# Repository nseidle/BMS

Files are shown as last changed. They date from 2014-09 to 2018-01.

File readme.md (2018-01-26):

Battery Management System
=======

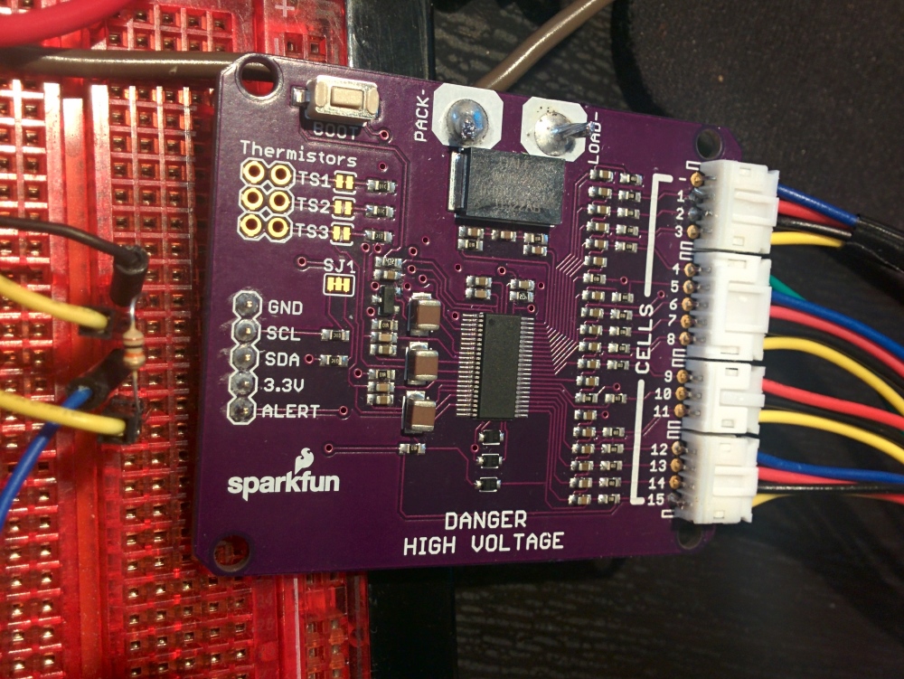
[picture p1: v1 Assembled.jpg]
BMS PCB Assembled v1


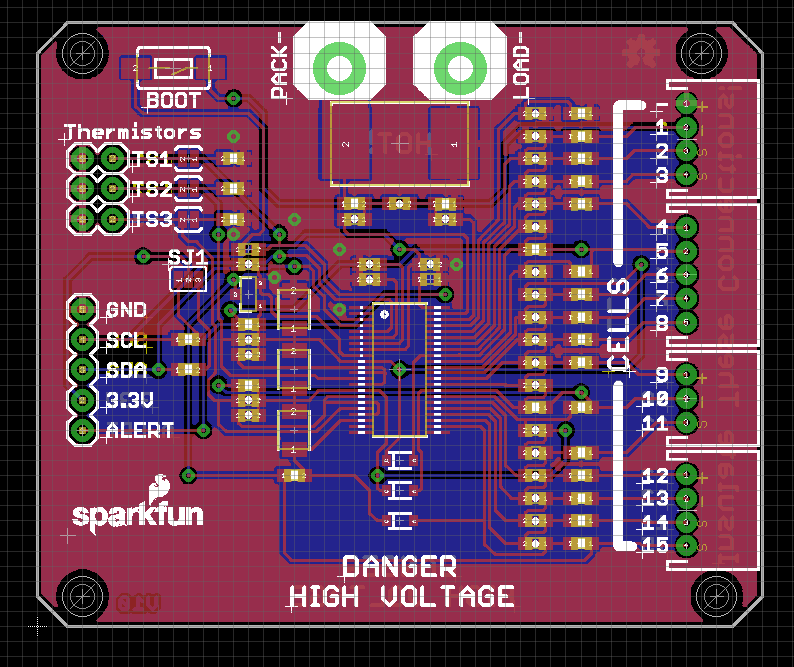
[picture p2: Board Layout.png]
BMS PCB Layout


This is a breakout board for the BQ76940. This configuration allows for 15 cells to be read. There is no safety cut off.

This is a dangerous board that exposes the user to over 48VDC and many amps. Please use responsibly.

v1 of the board is functional. Firmware is working. Most functions are written. 

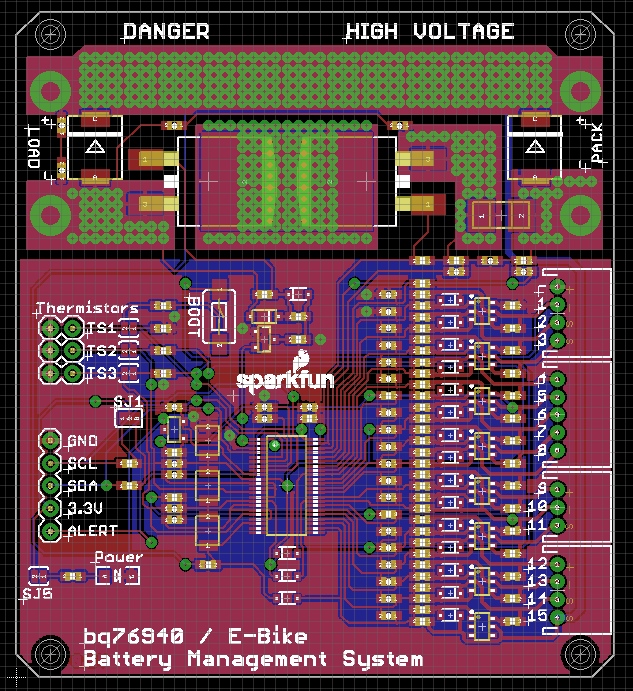
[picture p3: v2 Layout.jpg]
BMS PCB Layout v2


-> v2 of the board has full cutoff MOSFETs and charging MOSFETs. <-

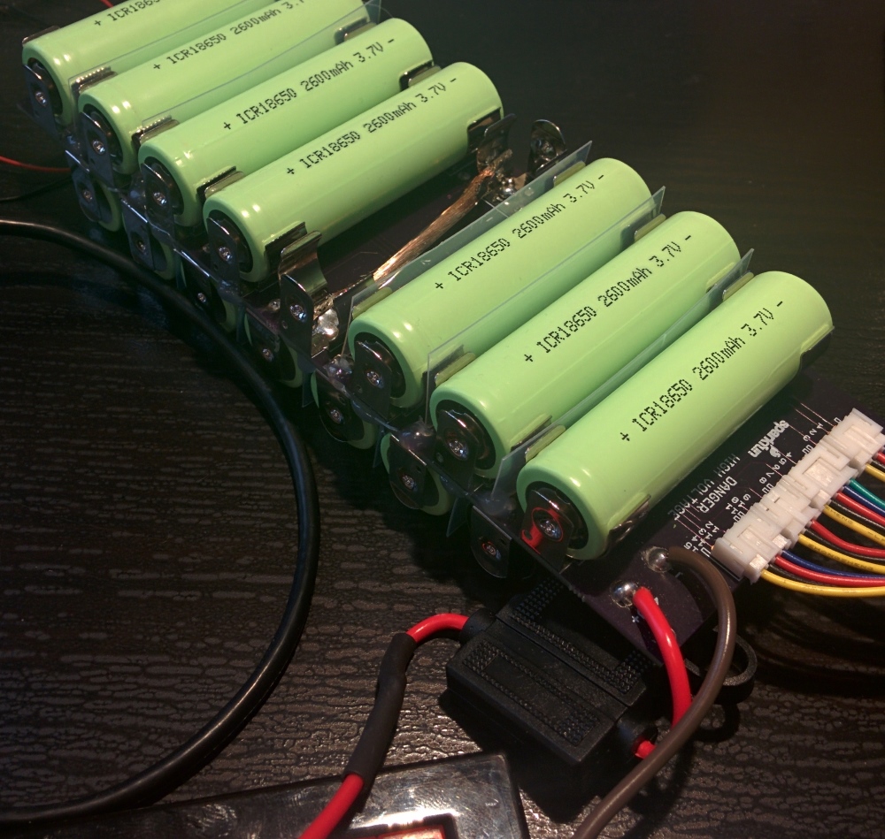
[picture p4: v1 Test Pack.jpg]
BMS Test Pack v1


v1 of the test pack works but has multiple errors that are fixed on v2. Number labels on the cells are reversed. Cells 9 and 14 were shorted to bring the voltage back down to 48V. The clips are very close together so plastic insulators were glued in place.

License Information
-------------------

This code is public domain but you buy me a beer if you use this and we meet someday ([Beerware license](http://en.wikipedia.org/wiki/Beerware)).

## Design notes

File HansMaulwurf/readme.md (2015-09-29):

Hans Maulwurf Project
=======

This is a university project created by Hans Maulwurf based on the original project by Nathan Seidle. This project documentation may aid others working with the BQ76940.

- Uses the ATmega168PA
- Programming was done in C with Linux in nano and the AVR-Tools (avr-gcc, avr-objcopy, avrdude, make)
- The system has 15 cells and max, 60 Volts

License Information
-------------------

Hans has agreed to release this portion of his project under the same licensing as the original project. This code is public domain but you buy me a beer if you use this and we meet someday ([Beerware license](http://en.wikipedia.org/wiki/Beerware)).

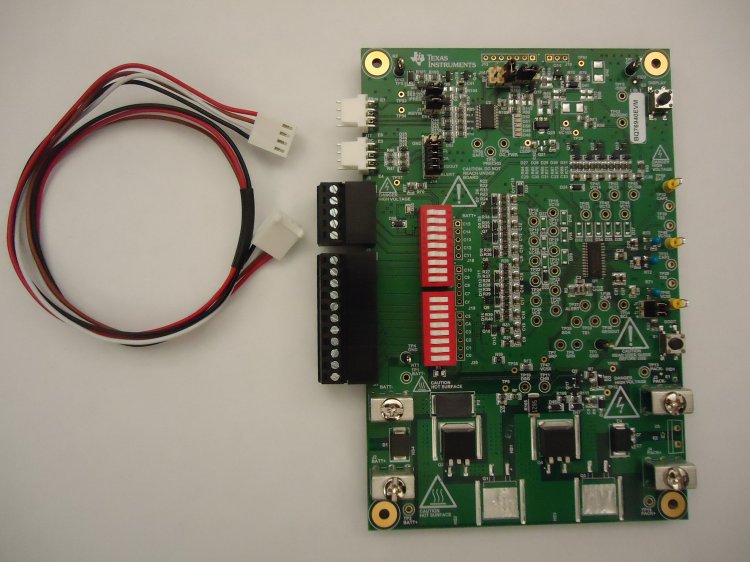
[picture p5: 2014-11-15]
datasheets/bq76940evm_bq76940evm.JPG

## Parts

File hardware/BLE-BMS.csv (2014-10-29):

Qty | Value | Device | Package | Parts | Description | PROD_ID | SKU | VALUE
1 | .001 | RESISTORWSR | 4527 | R29
3 | 0.1uF | 0.1UF-25V(+80/-20%)(0603) | 0603-CAP | C29, C30, C31 | CAP-00810 | CAP-00810 |  | 0.1uF
5 | 100 | 100OHM1/10W1%(0603) | 0603-RES | R3, R27, R28, R30, R31 | RES-07863 | RES-07863 |  | 100
5 | 10k | 10KOHM1/10W1%(0603)0603 | 0603-RES | R1, R2, R32, R33, R34 | RES-00824 | RES-00824 |  | 10K
3 | 10uF | 10UF50V20%(1210) | 1210 | C32, C33, C34 | CAP-09824 | CAP-09824 |  | 10uF
18 | 1K | 1KOHM1/10W1%(0603) | 0603-RES | R4, R5, R6, R10, R11, R12, R13, R14, R15, R16, R17, R18, R19, R20, R21, R22, R23, R24 | RES-07856 | RES-07856 |  | 1K
22 | 1uF | 1.0UF-16V-10%(0603) | 0603-CAP | C4, C6, C7, C8, C11, C12, C13, C14, C15, C16, C17, C18, C19, C20, C21, C22, C23, C24, C25, C26, C27, C28 | CAP-00868 | CAP-00868 |  | 1.0uF
2 | 4.7k | 4.7KOHM1/10W1%(0603) | 0603 | R25, R26 | RES-07857 | RES-07857
1 | 4.7uF | 4.7UF-6.3V-10%(0603)0603 | 0603-CAP | C1 | CAP-08280 | CAP-08280 |  | 4.7uF
3 | 4700pF | 4.7NF-50V-10%(0603) | 0603-CAP | C2, C9, C10 | CAP-11378 | CAP-11378 |  | 4.7nF
3 | BAS16 | DIODESOD | SOD-323 | D1, D2, D3 | Diode | DIO-09646
1 | BOOT | SWITCH-MOMENTARY-2-SMD-1101NE | TACTILE-SWITCH-1101NE | S1 | Various NO switches-
1 | BQ7694040 | BQ7694040 | 44-TSSOP | U1 | Description: bq769x0
1 | BSS138 | MOSFET-NCHANNELBSS138 | SOT23-3 | Q1 | Common NMOSFET Parts | TRANS-00830

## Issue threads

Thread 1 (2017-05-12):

v2 BOM ?

pheex, 2017-05-12:
Hi,

Can you add the bom list for the v2 version ?

Thanks

nseidle, 2017-05-17:
You can get most of the part values from the eagle files and schematic. I'm sorry I don't have a proper BOM or part #s for some of the parts. This is an old project that I can't maintain going forward but I would be thrilled to have someone take it over.

Closed 2017-05-17.

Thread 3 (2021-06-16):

BMS v2

xromansx, 2021-06-16:
Do you have any real photos of BMS V2 I would like to order some would like to see how they look like, this small resistors are not for balancing so there are no balancer resistors how do you cell balancing and what you think about LTC6804 instead of BQ76940.

Thansk

Jafar-ting91, 2023-01-23:
Hallo habe das gleiche problemm  bort ist aufgebaut nur ohne ausgleich FETS   code funktioniert   nur power fets  schalten nicht .

Serial monitor
ADC Already Enabled
gain: 0.38uV/LSB
offset: 44mV
Undervoltage trip: 2.51V
Overvoltage trip: 4.18V
New undervoltage trip: 2.51V
New overvoltage trip: 4.18V
bq76940 initialized!
Voltages:
[1]3.06 [2]3.06 [3]3.06 [4]3.06 [5]3.06
[6]3.06 [7]3.06 [8]3.06 [9]0.07 [10]3.06
[11]3.06 [12]3.06 [13]3.06 [14]0.07 [15]0.00
Die temp = 22
PackV = 40.32
PackV manual = 36.80
Die temp = 22
PackV = 40.32
PackV manual = 36.80

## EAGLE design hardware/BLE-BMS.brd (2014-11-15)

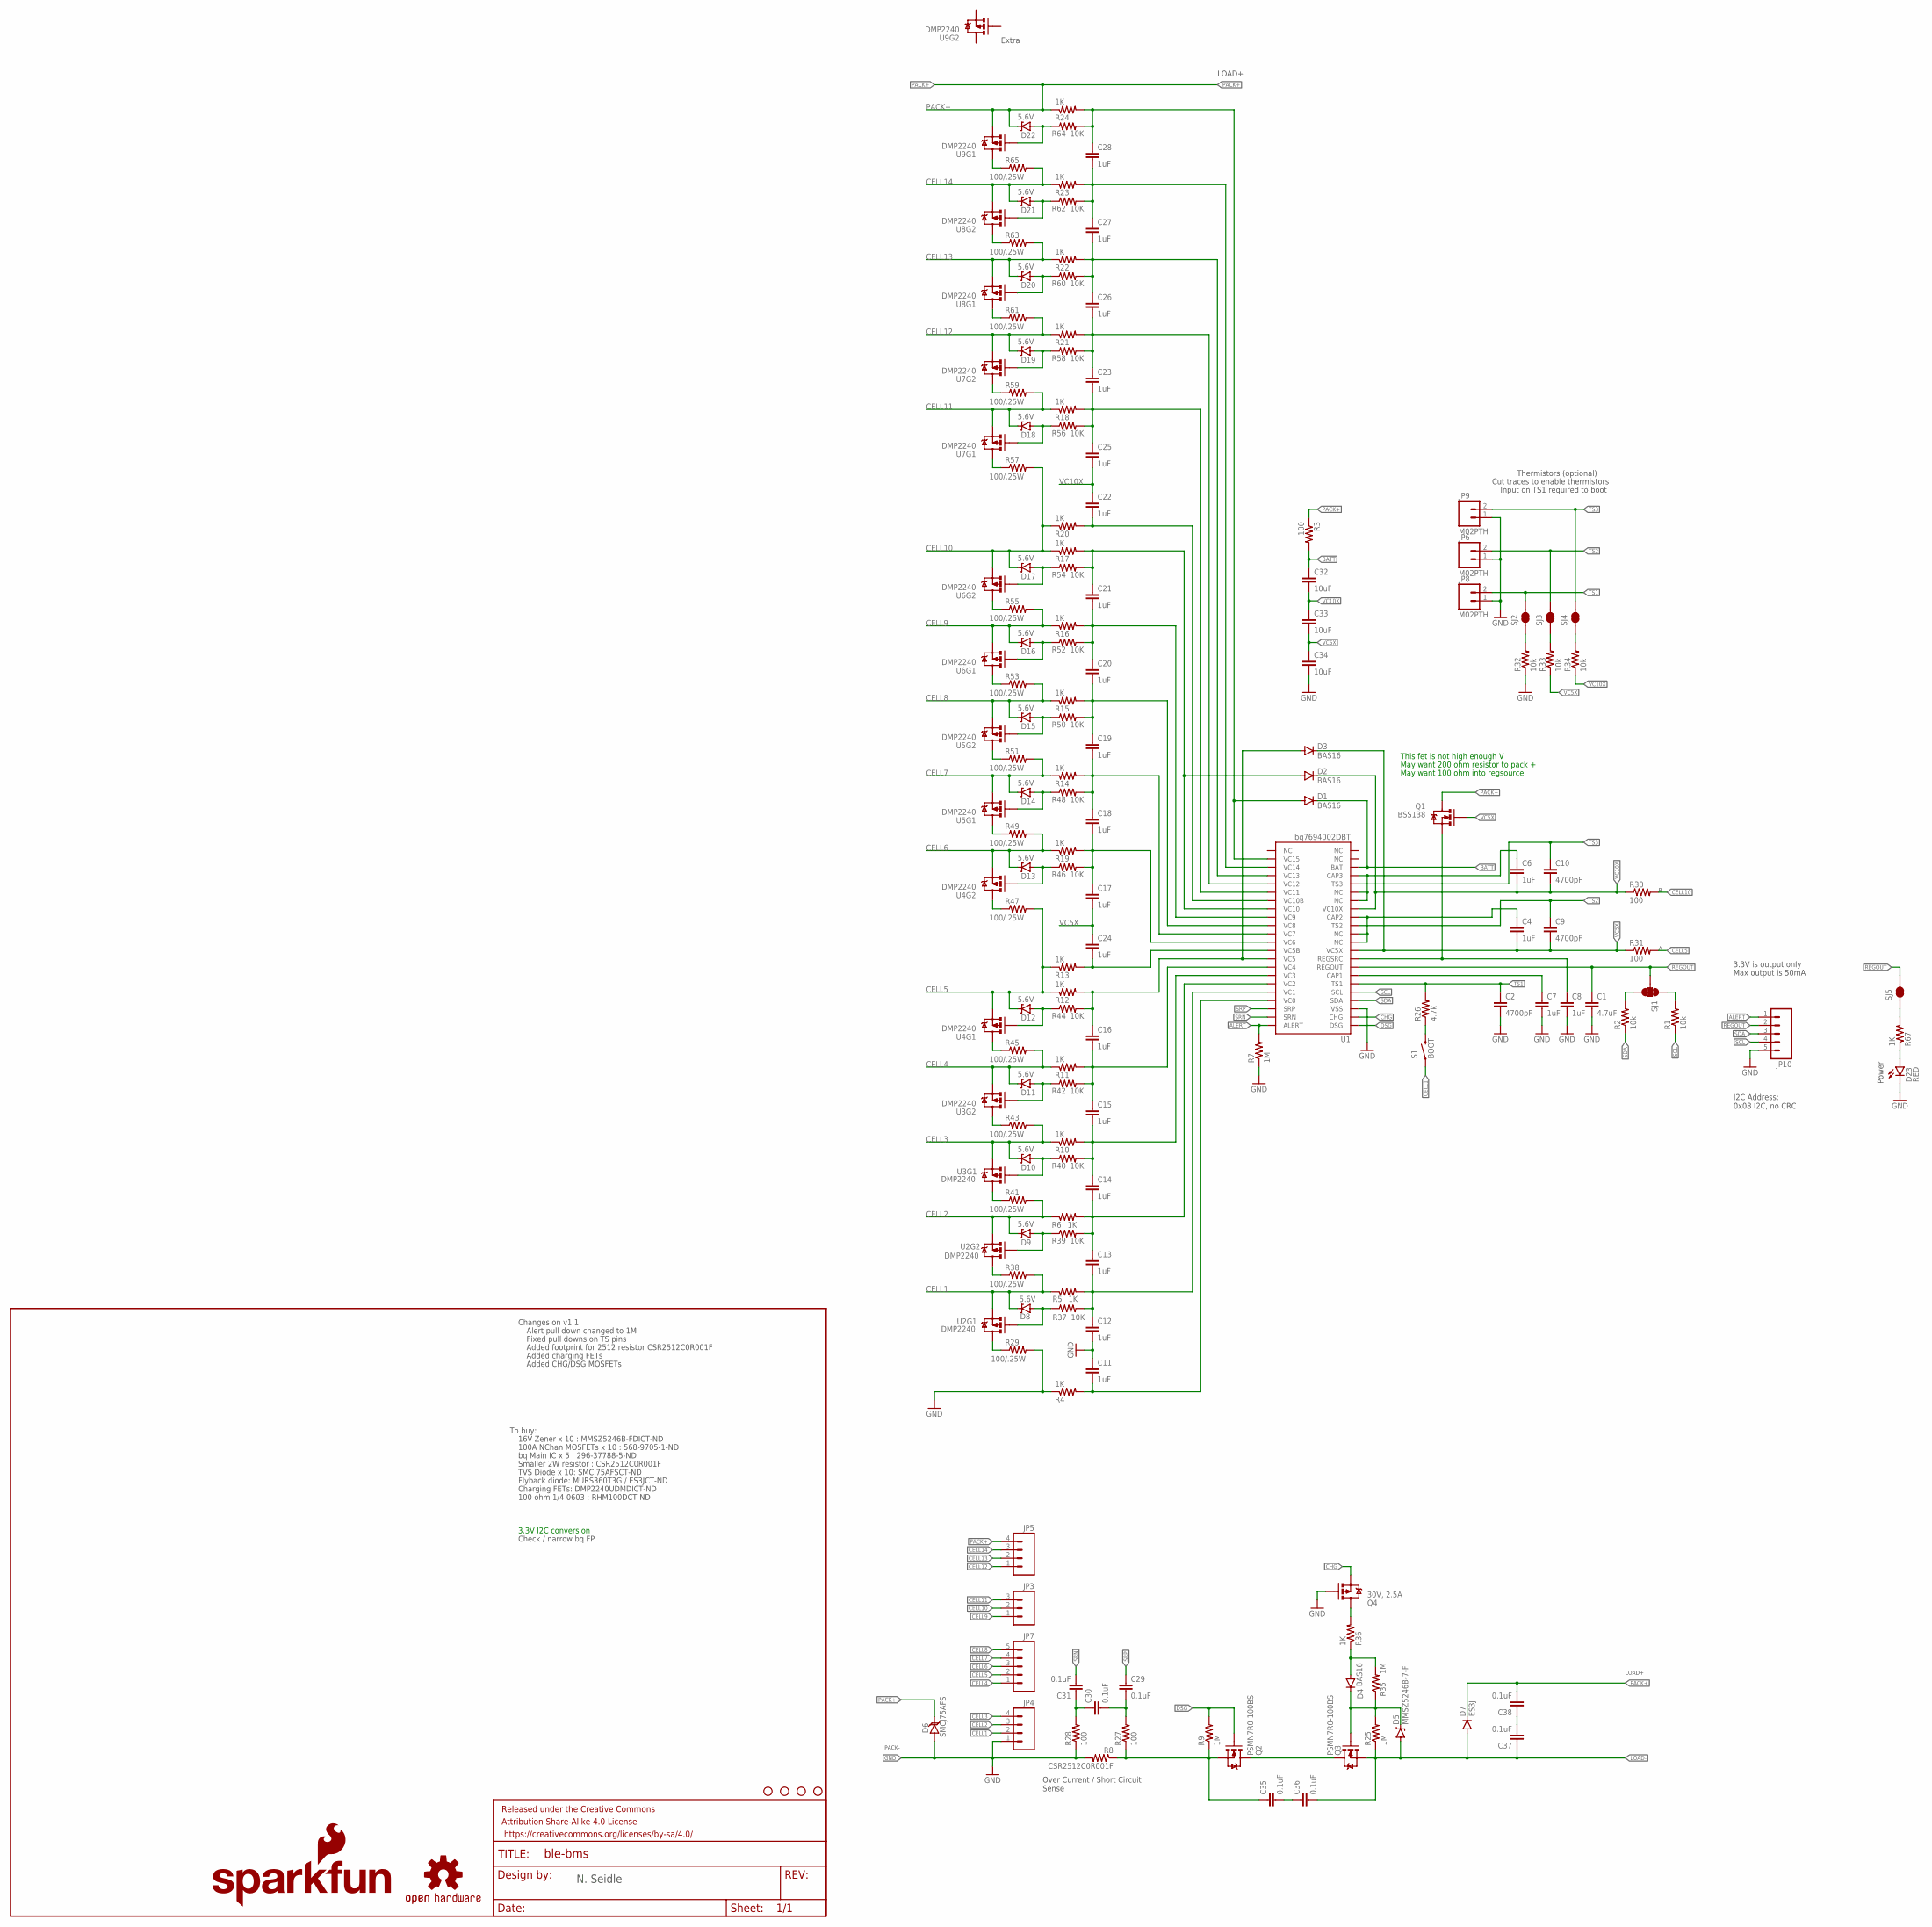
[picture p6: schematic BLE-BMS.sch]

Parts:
C1: 4.7uF; 0603-CAP
C2, C9, C10: 4700pF; 0603-CAP
C4, C6, C7, C8, C11, C12, C13, C14, C15, C16, C17, C18, C19, C20, C21, C22, C23, C24, C25, C26, C27, C28: 1uF; 0603-CAP
C29, C30, C31, C35, C36, C37, C38: 0.1uF; 0603-CAP
C32, C33, C34: 10uF; 1210
D1, D2, D3, D4: BAS16; SOD-323
D5: MMSZ5246B-7-F; SOD-123
D6: SMCJ75AFS; SMC
D7: ES3J; SMC
D8, D9, D10, D11, D12, D13, D14, D15, D16, D17, D18, D19, D20, D21, D22: 5.6V; SOD-323
D23: RED; LED-1206
FRAME1: FRAME-LETTER; CREATIVE_COMMONS
JP3: M03JST-PTH; JST-3-PTH
JP4, JP5: M04JST-PTH; JST-4-PTH
JP6, JP8, JP9: M02PTH; 1X02
JP7: M05JST; JST-5-PTH
JP10: M05PTH; 1X05
LOGO1: SFE_LOGO_NAME_FLAME.1_INCH; SFE_LOGO_NAME_FLAME_.1
Q1: BSS138; SOT23-3
Q2, Q3: PSMN7R0-100BS; TO-263/D2PAK
Q4: 30V, 2.5A; SOT23-3
R1, R2, R32, R33, R34: 10k; 0603-RES
R3, R27, R28, R30, R31: 100; 0603-RES
R4, R5, R6, R10, R11, R12, R13, R14, R15, R16, R17, R18, R19, R20, R21, R22, R23, R24, R36, R67: 1K; 0603-RES
R7, R9, R25, R35: 1M; 0603-RES
R8: CSR2512C0R001F; 2512
R26: 4.7k; 0603-RES
R29, R38, R41, R43, R45, R47, R49, R51, R53, R55, R57, R59, R61, R63, R65: 100/.25W; 0603-RES
R37, R39, R40, R42, R44, R46, R48, R50, R52, R54, R56, R58, R60, R62, R64: 10K; 0603-RES
S1: BOOT; TACTILE-SWITCH-1101NE
SJ1: JUMPER-PAD-3-NC_BY_TRACE; PAD-JUMPER-3-3OF3_NC_BY_TRACE_YES_SILK_FULL_BOX
SJ2, SJ3, SJ4, SJ5: JUMPER-PAD-2-NC_BY_TRACE; PAD-JUMPER-2-NC_BY_TRACE_YES_SILK
STANDOFF1, STANDOFF2, STANDOFF3, STANDOFF4: STAND-OFF
U1: bq7694002DBT; 44-TSSOP
U2, U3, U4, U5, U6, U7, U8, U9: DMP2240; SOT26
U$7: OSHW-LOGOS; OSHW-LOGO-S

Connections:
ALERT: JP10.1, R7.2, U1.44 (ALERT)
BATT: C32.1, D1.C, R3.2, U1.20 (BAT)
CAP2: C4.1, U1.11 (NC), U1.12 (NC), U1.14 (CAP2)
CAP3: C6.1, U1.16 (NC), U1.17 (NC), U1.19 (CAP3)
CELL1: D8.C, JP4.2, R5.1, R38.2, S1.1, U2.S1 (S)
CELL2: D9.C, JP4.3, R6.1, R41.2, U2.S2 (S)
CELL3: D10.C, JP4.4, R10.1, R43.2, U3.S1 (S)
CELL4: D11.C, JP7.1, R11.1, R45.2, U3.S2 (S)
CELL5: D12.C, JP7.2, R12.1, R13.1, R31.2, R47.2, U4.S1 (S)
CELL6: D13.C, JP7.3, R19.1, R49.2, U4.S2 (S)
CELL7: D14.C, JP7.4, R14.1, R51.2, U5.S1 (S)
CELL8: D15.C, JP7.5, R15.1, R53.2, U5.S2 (S)
CELL9: D16.C, JP3.1, R16.1, R55.2, U6.S1 (S)
CELL10: D17.C, JP3.2, R17.1, R20.1, R30.2, R57.2, U6.S2 (S)
CELL11: D18.C, JP3.3, R18.1, R59.2, U7.S1 (S)
CELL12: D19.C, JP5.1, R21.1, R61.2, U7.S2 (S)
CELL13: D20.C, JP5.2, R22.1, R63.2, U8.S1 (S)
CELL14: D21.C, JP5.3, R23.1, R65.2, U8.S2 (S)
CHG: Q4.2 (S), U1.2 (CHG)
CHG_CTL: D4.C, D5.C, Q3.1 (G), R25.2, R35.1
DSG: Q2.1 (G), R9.2, U1.1 (DSG)
GND: C1.2, C2.2, C7.2, C8.2, C11.1, C12.2, C34.2, D6.A, D23.C, JP4.1, JP6.1, JP8.1, JP9.1, JP10.5, Q4.1 (G), R4.1, R7.1, R8.2, R28.1, R29.2, R32.1, U1.3 (VSS)
LOAD1: Q2.2 (D), Q3.2 (D)
LOAD2: C35.1, Q2.3 (S), R8.1, R9.1, R27.1
LOAD-: C36.2, C37.1, D5.A, D7.A, Q3.3 (S), R25.1
unnamed: D8.A, R37.1, U2.G1 (G)
unnamed: Q4.3 (D), R36.2
unnamed: R32.2, SJ2.1
unnamed: R29.1, U2.D1 (D)
unnamed: D9.A, R39.1, U2.G2 (G)
unnamed: C35.2, C36.1
unnamed: D4.A, R35.2, R36.1
unnamed: R38.1, U2.D2 (D)
unnamed: C37.2, C38.1
unnamed: R2.2, SJ1.3
unnamed: R1.2, SJ1.1
unnamed: D10.A, R40.1, U3.G1 (G)
unnamed: R41.1, U3.D1 (D)
unnamed: D11.A, R42.1, U3.G2 (G)
unnamed: R43.1, U3.D2 (D)
unnamed: D12.A, R44.1, U4.G1 (G)
unnamed: R45.1, U4.D1 (D)
unnamed: D13.A, R46.1, U4.G2 (G)
unnamed: R47.1, U4.D2 (D)
unnamed: R49.1, U5.D1 (D)
unnamed: D14.A, R48.1, U5.G1 (G)
unnamed: R51.1, U5.D2 (D)
unnamed: D15.A, R50.1, U5.G2 (G)
unnamed: R33.2, SJ3.1
unnamed: C7.1, U1.7 (CAP1)
unnamed: R26.1, S1.2
unnamed: R34.2, SJ4.1
unnamed: C29.2, C30.2, R27.2
unnamed: C30.1, C31.1, R28.2
unnamed: R53.1, U6.D1 (D)
unnamed: D16.A, R52.1, U6.G1 (G)
unnamed: D17.A, R54.1, U6.G2 (G)
unnamed: R55.1, U6.D2 (D)
unnamed: D18.A, R56.1, U7.G1 (G)
unnamed: R57.1, U7.D1 (D)
unnamed: D19.A, R58.1, U7.G2 (G)
unnamed: R59.1, U7.D2 (D)
unnamed: D20.A, R60.1, U8.G1 (G)
unnamed: R61.1, U8.D1 (D)
unnamed: D21.A, R62.1, U8.G2 (G)
unnamed: R63.1, U8.D2 (D)
unnamed: D22.A, R64.1, U9.G1 (G)
unnamed: R65.1, U9.D1 (D)
unnamed: D23.A, R67.1
unnamed: R67.2, SJ5.1
PACK+: C38.2, D6.C, D7.C, D22.C, JP5.4, Q1.3 (D), R3.1, R24.1, U9.S1 (S)
REGOUT: C1.1, JP10.2, SJ1.2, SJ5.2, U1.8 (REGOUT)
REGSRC: C8.1, Q1.2 (S), U1.9 (REGSRC)
SCL: JP10.4, R1.1, U1.5 (SCL)
SDA: JP10.3, R2.1, U1.4 (SDA)
SRN: C31.2, U1.43 (SRN)
SRP: C29.1, U1.42 (SRP)
TS1: C2.1, JP8.2, R26.2, SJ2.2, U1.6 (TS1)
TS2: C9.1, JP6.2, SJ3.2, U1.13 (TS2)
TS3: C10.1, JP9.2, SJ4.2, U1.18 (TS3)
VC0: C11.2, R4.2, U1.41 (VC0)
VC1: C12.1, C13.2, R5.2, R37.2, U1.40 (VC1)
VC2: C13.1, C14.2, R6.2, R39.2, U1.39 (VC2)
VC3: C14.1, C15.2, R10.2, R40.2, U1.38 (VC3)
VC4: C15.1, C16.2, R11.2, R42.2, U1.37 (VC4)
VC5: C16.1, D3.A, R12.2, R44.2, U1.36 (VC5)
VC5B: C24.2, R13.2, U1.35 (VC5B)
VC5X: C4.2, C9.2, C17.2, C24.1, C33.2, C34.1, D3.C, Q1.1 (G), R31.1, R33.1, U1.10 (VC5X)
VC6: C17.1, C18.2, R19.2, R46.2, U1.34 (VC6)
VC7: C18.1, C19.2, R14.2, R48.2, U1.33 (VC7)
VC8: C19.1, C20.2, R15.2, R50.2, U1.32 (VC8)
VC9: C20.1, C21.2, R16.2, R52.2, U1.31 (VC9)
VC10: C21.1, D2.A, R17.2, R54.2, U1.30 (VC10)
VC10B: C22.2, R20.2, U1.29 (VC10B)
VC10X: C6.2, C10.2, C22.1, C25.2, C32.2, C33.1, D2.C, R30.1, R34.1, U1.15 (VC10X)
VC11: C23.2, C25.1, R18.2, R56.2, U1.28 (VC11)
VC12: C23.1, C26.2, R21.2, R58.2, U1.27 (VC12)
VC13: C26.1, C27.2, R22.2, R60.2, U1.26 (VC13)
VC14: C27.1, C28.2, R23.2, R62.2, U1.25 (VC14)
VC15: C28.1, D1.A, R24.2, R64.2, U1.24 (VC15)

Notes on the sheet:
Thermistors (optional)
Over Current / Short Circuit Sense
Cut traces to enable thermistors
Input on TS1 required to boot
Added footprint for 2512 resistor CSR2512C0R001F
3.3V I2C conversion
I2C Address: 0x08 I2C, no CRC
This fet is not high enough V
May want 200 ohm resistor to pack +
May want 100 ohm into regsource
Changes on v1.1:
Alert pull down changed to 1M
Fixed pull downs on TS pins
PACK-
To buy:
16V Zener x 10 : MMSZ5246B-FDICT-ND
100A NChan MOSFETs x 10 : 568-9705-1-ND
bq Main IC x 5 : 296-37788-5-ND
Smaller 2W resistor : CSR2512C0R001F
TVS Diode x 10: SMCJ75AFSCT-ND
Flyback diode: MURS360T3G / ES3JCT-ND
LOAD+
Charging FETs: DMP2240UDMDICT-ND
100 ohm 1/4 0603 : RHM100DCT-ND
Check / narrow bq FP
N. Seidle
Added charging FETs
Added CHG/DSG MOSFETs
Extra
3.3V is output only
Max output is 50mA
Power

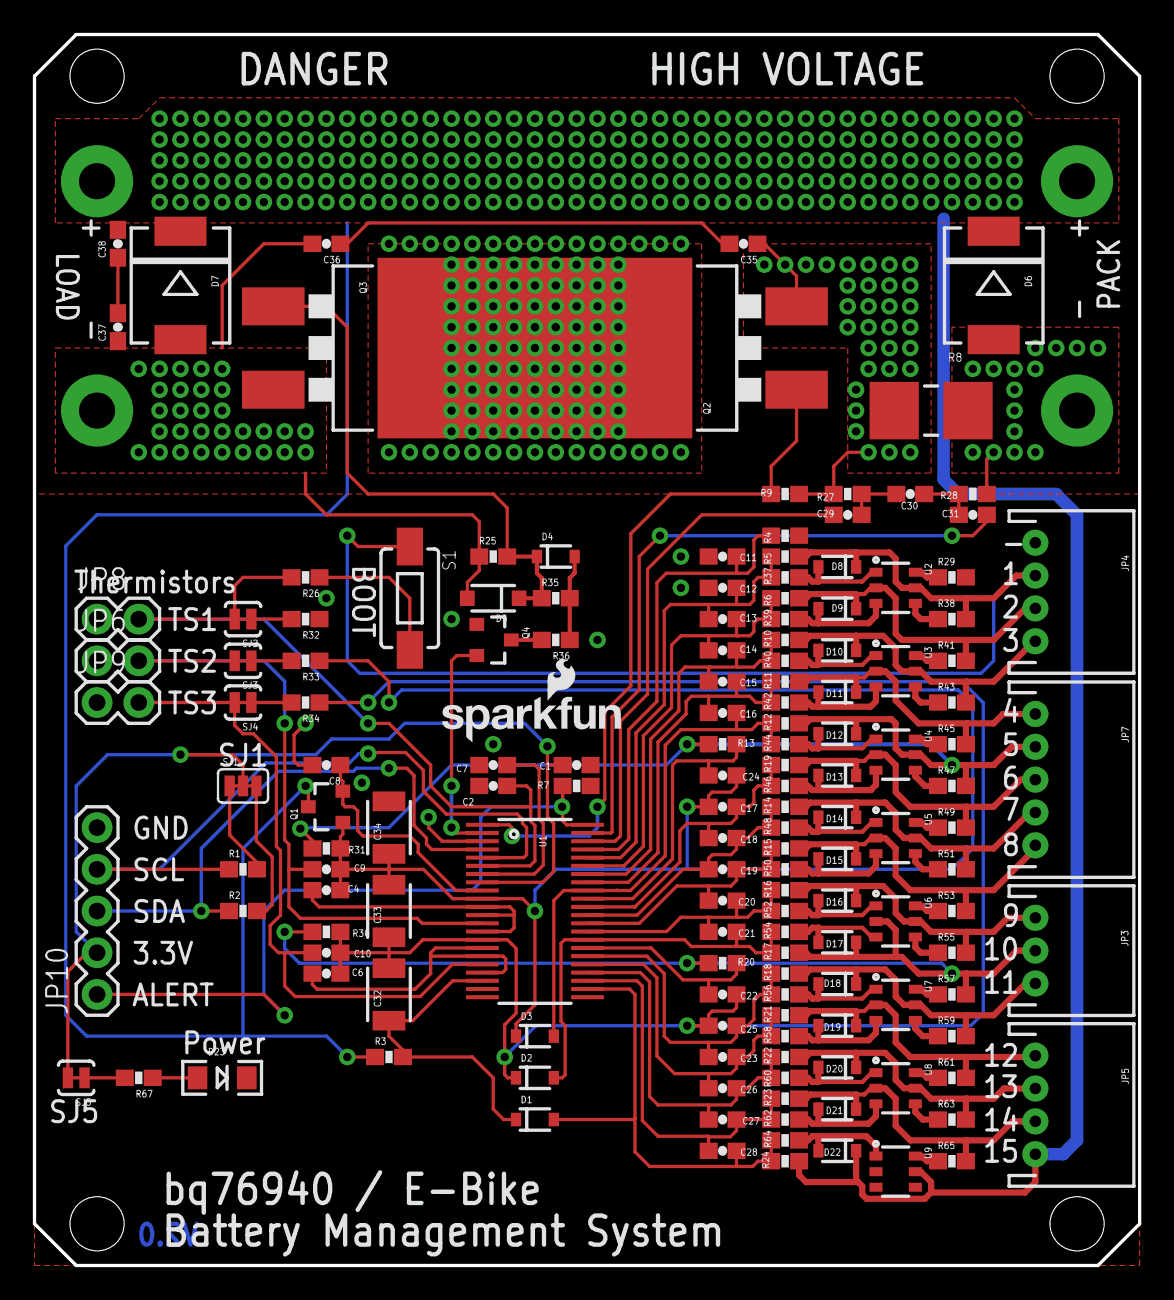
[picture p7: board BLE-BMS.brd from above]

Board: 2 copper layers, 67.3 x 75.0 mm, 159 parts (1 on the bottom side), 100 nets.

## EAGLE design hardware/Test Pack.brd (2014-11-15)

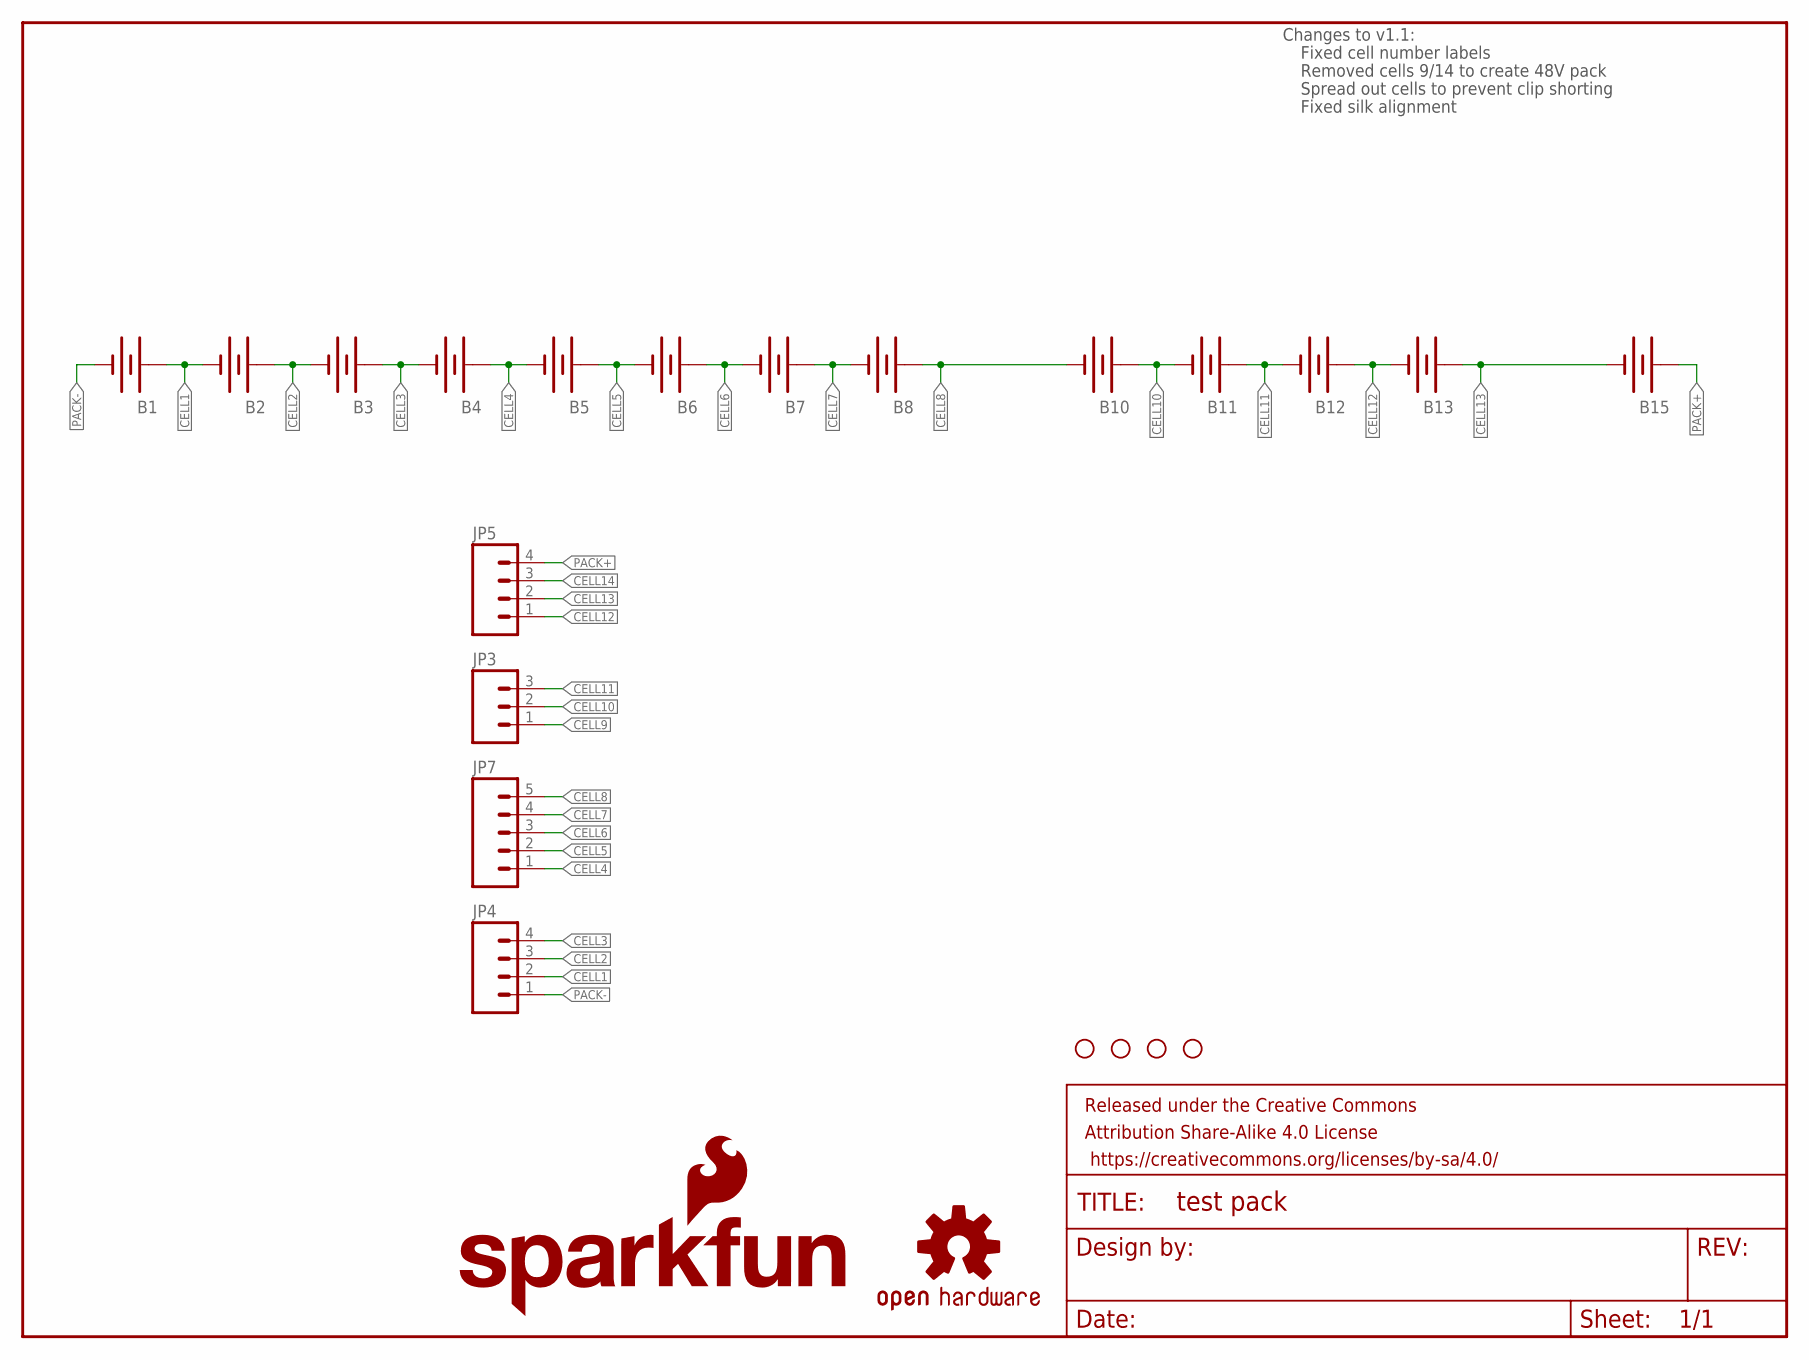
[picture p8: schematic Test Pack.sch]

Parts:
B1, B2, B3, B4, B5, B6, B7, B8, B10, B11, B12, B13, B15: BATTERY18650; BATTERY_18650-HOLDER
FRAME1: FRAME-LETTER; CREATIVE_COMMONS
JP3: M03JST-PTH; JST-3-PTH
JP4, JP5: M04JST-PTH; JST-4-PTH
JP7: M05JST; JST-5-PTH
LOGO1: SFE_LOGO_NAME_FLAME.1_INCH; SFE_LOGO_NAME_FLAME_.1
STANDOFF1, STANDOFF2, STANDOFF3, STANDOFF4: STAND-OFF
U$7: OSHW-LOGOS; OSHW-LOGO-S

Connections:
CELL1: B1.PWR@1 (+), B2.GND@1 (-), JP4.2
CELL2: B2.PWR@1 (+), B3.GND@1 (-), JP4.3
CELL3: B3.PWR@1 (+), B4.GND@1 (-), JP4.4
CELL4: B4.PWR@1 (+), B5.GND@1 (-), JP7.1
CELL5: B5.PWR@1 (+), B6.GND@1 (-), JP7.2
CELL6: B6.PWR@1 (+), B7.GND@1 (-), JP7.3
CELL7: B7.PWR@1 (+), B8.GND@1 (-), JP7.4
CELL8: B8.PWR@1 (+), B10.GND@1 (-), JP7.5
CELL9: JP3.1
CELL10: B10.PWR@1 (+), B11.GND@1 (-), JP3.2
CELL11: B11.PWR@1 (+), B12.GND@1 (-), JP3.3
CELL12: B12.PWR@1 (+), B13.GND@1 (-), JP5.1
CELL13: B13.PWR@1 (+), B15.GND@1 (-), JP5.2
CELL14: JP5.3
PACK+: B15.PWR@1 (+), JP5.4
PACK-: B1.GND@1 (-), JP4.1

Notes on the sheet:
Changes to v1.1:
Fixed cell number labels
Removed cells 9/14 to create 48V pack
Spread out cells to prevent clip shorting
Fixed silk alignment

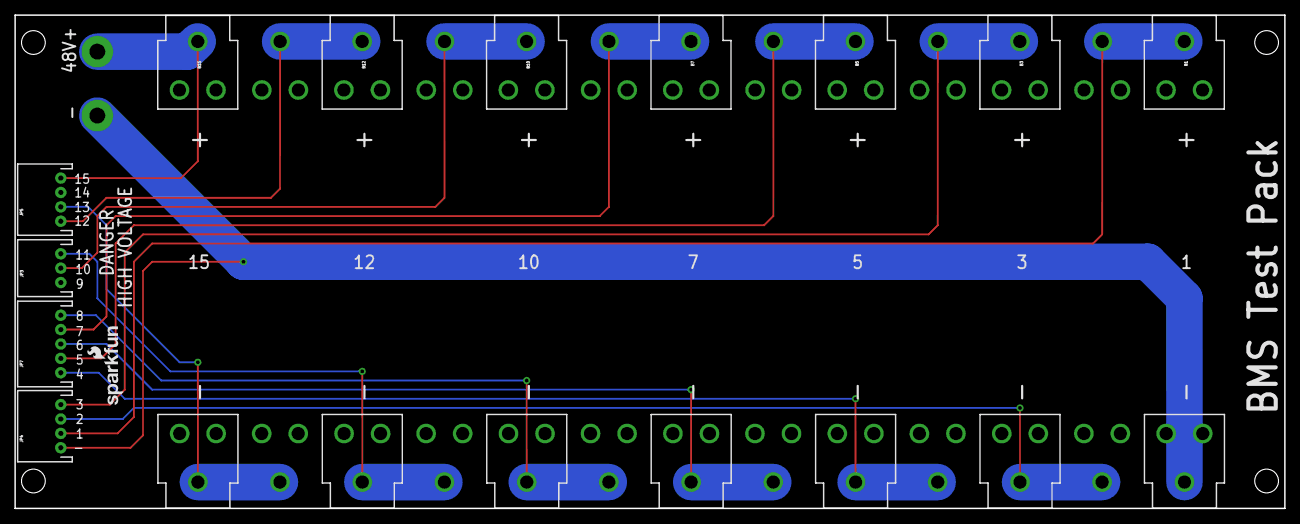
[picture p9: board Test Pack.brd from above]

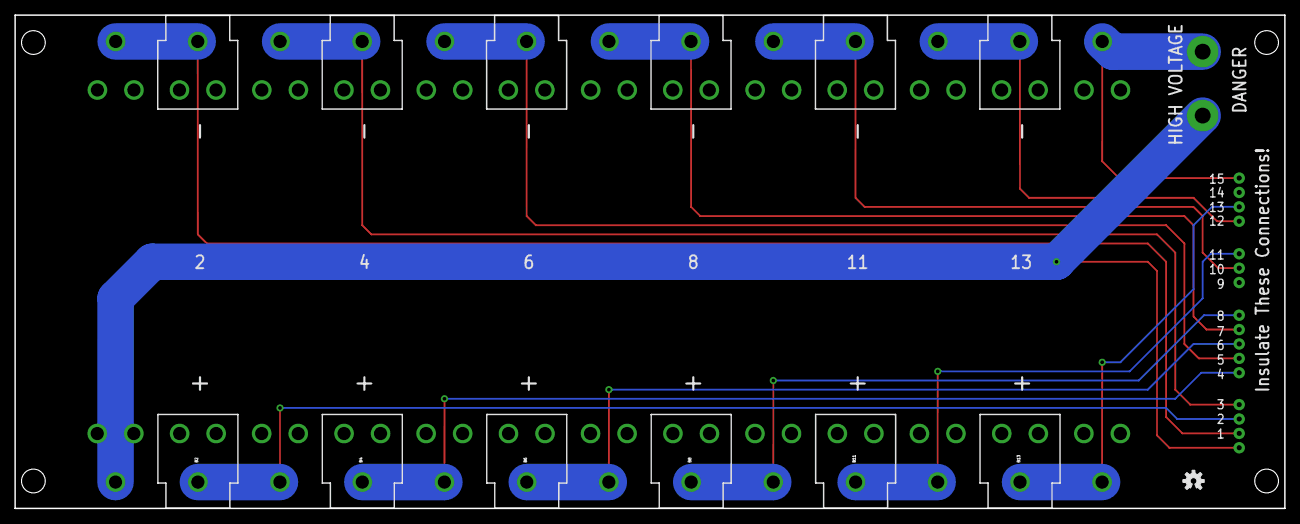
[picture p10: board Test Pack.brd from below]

Board: 2 copper layers, 176.5 x 68.6 mm, 24 parts (7 on the bottom side), 14 nets.

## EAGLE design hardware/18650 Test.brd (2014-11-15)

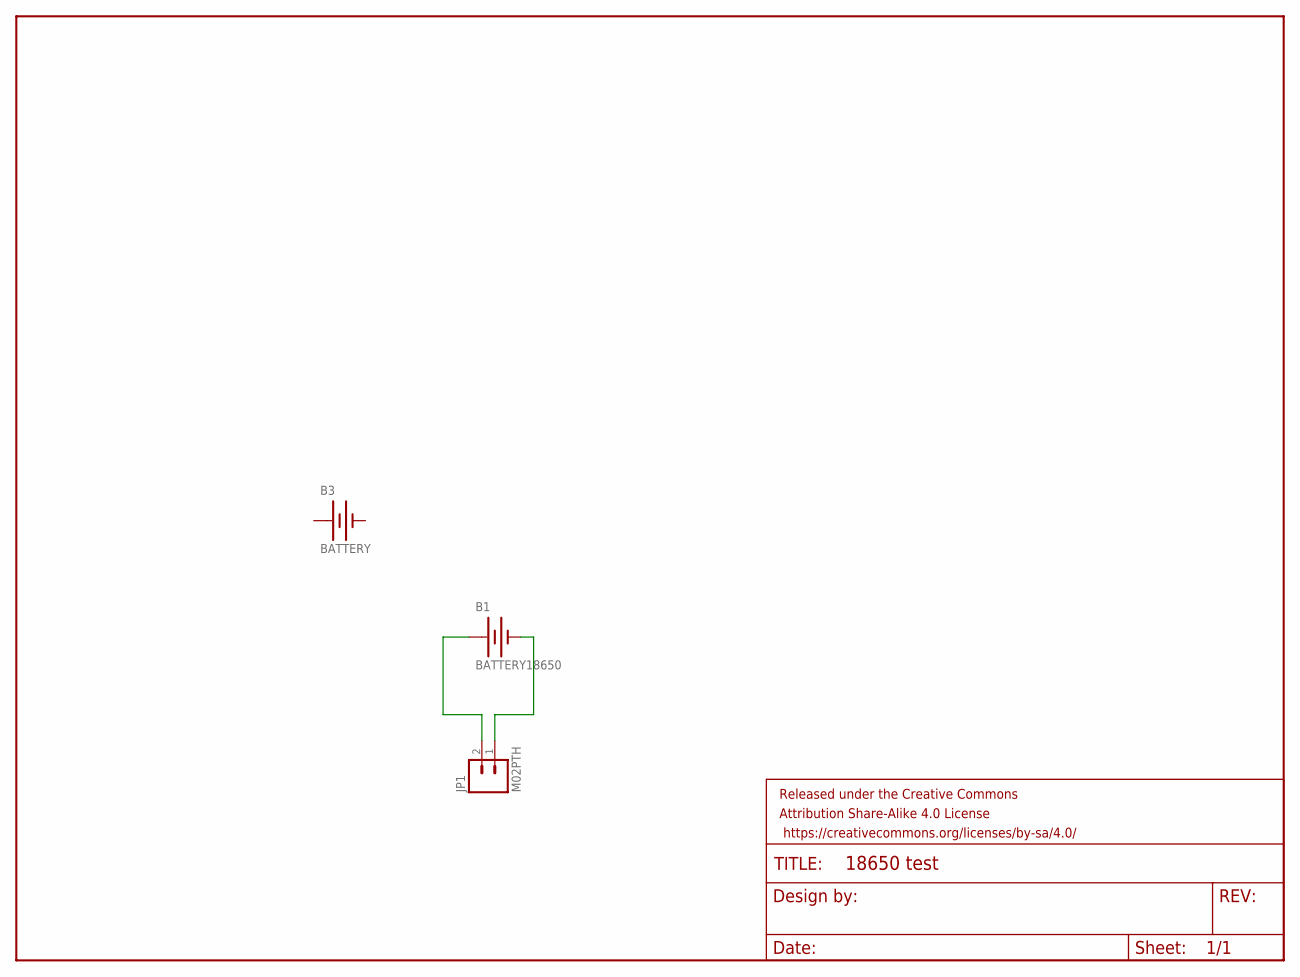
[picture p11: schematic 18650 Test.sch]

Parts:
B1: BATTERY18650; 18650-HOLDER
B3: BATTERY; 18650-TEST
FRAME1: FRAME-LETTER; CREATIVE_COMMONS
JP1: M02PTH; 1X02

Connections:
+: B3.PWR@4 (+)
-: B3.PWR@3 (-)
GND: B1.GND@1 (-), JP1.1
VCC: B1.PWR@1 (+), JP1.2

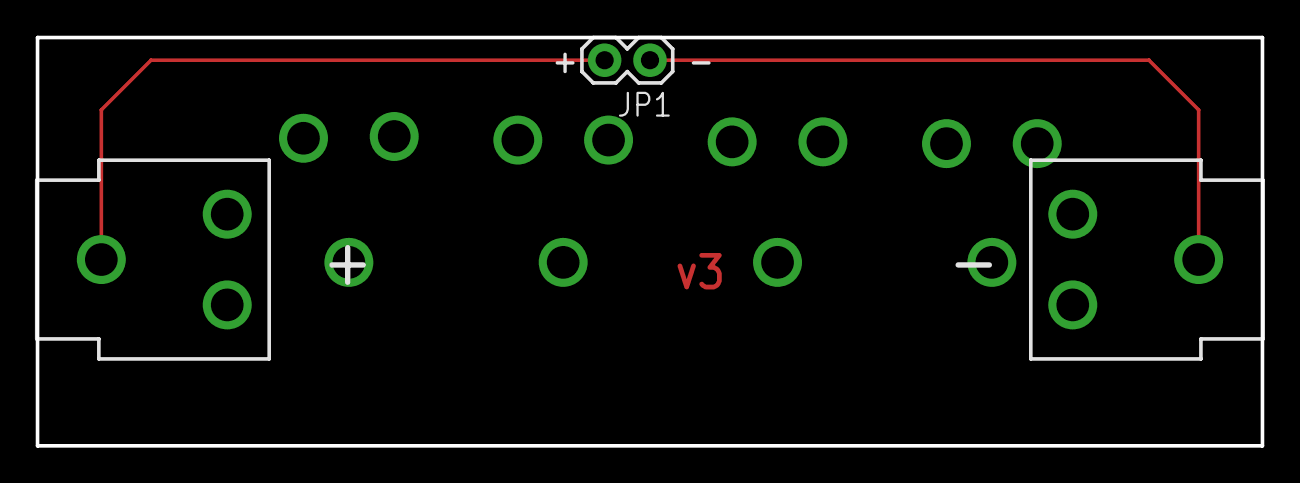
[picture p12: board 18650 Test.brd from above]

Board: 2 copper layers, 68.6 x 22.9 mm, 4 parts (1 on the bottom side), 2 nets.

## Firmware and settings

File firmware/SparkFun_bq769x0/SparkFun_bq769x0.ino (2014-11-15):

/*
 Library and example code for the bq76920, bq76930, and bq76940 battery management IC.
 By: Nathan Seidle
 SparkFun Electronics
 Date: September 26th, 2014
 License: This code is public domain but you buy me a beer if you use this and we meet someday (Beerware license).
 
 The bq769x0 series ICs manage large multi-cell battery packs for 12/18/24/36 and 48V systems. This code focuses on the 
 largest IC the bq76940 but most features should work on the smaller pack controllers.
 
 The bq76940 measures individual cell voltages, coulomb counter, three thermistor temperature sensors, and a bunch of
 other nice features.
 
 Here's how to hook up the Arduino pins to the bq76940 breakout board
 
 Arduino pin A4 (or SDA) -> bq769x0 SDA
 A5 (or SCL) -> SCL
 2 -> ALERT
 3.3V -> 3.3V
 GND -> GND
 
 Connecting the ALERT pin is recommended but is not requied. The alert pin will be raised if there is a fault condition.
 
 TODO:
 Get coulomb counter into global variable that increases after each IRQ
 Establish the direction of counter. Does negative mean we are charging or driving? 
 
 */

#include <Wire.h>
#include "SparkFun_BQ769x0.h"

//The bq769x0 without CRC has the 7-bit address 0x08. The bq769x0 with CRC has the address 0x18. 
//Please see the datasheet for more info
int bqI2CAddress = 0x08; //7-bit I2C address

//My pack is a 15 cell lipo that runs at 48V. Your pack may vary. Read the datasheet!
//This code is written for the bq76940. The bq76940 supports 9 to 15 cells.
#define NUMBER_OF_CELLS 15

//Max number of ms before timeout error. 100 is pretty good
#define MAX_I2C_TIME 100

volatile boolean bq769x0_IRQ_Triggered = false; //Keeps track of when the Alert pin has been raised

float gain = 0; //These are two internal factory set values.
int offset = 0; //We read them once at boot up and use them in many functions

long lastTime; //Used to blink the status LED

long totalCoulombCount = 0; //Keeps track of overall pack fuel gauage

float cellVoltage[NUMBER_OF_CELLS + 1]; //Keeps track of the cell voltages

//GPIO declarations
//-=-=-=-=-=-=-=-=-=-=-=-=-=-=-=-=-=-=-=-=-=-=-=-=

byte irqPin = 2; //Interrupt enabled, connected to bq pin ALERT
byte statLED = 13; //Ob board status LED

//-=-=-=-=-=-=-=-=-=-=-=-=-=-=-=-=-=-=-=-=-=-=-=-=

void setup()
{
  Serial.begin(9600);
  Serial.println("bq76940 example");

  Wire.begin(); //Start I2C communication

    pinMode(statLED, OUTPUT);
  digitalWrite(statLED, LOW); //Turn off the LED for now

  if(initBQ(2) == false) //Call init with pin 2 (IRQ0) or 3 (IRQ1)
  {
    Serial.println("bq76940 failed to respond - check your wiring");
    Serial.println("Hanging.");
    while(1);
  }
  else
  {
    Serial.println("bq76940 initialized!");
  }

  lastTime = millis();

  //Testing

  //  Serial.println();

  /*
  readCoulombCounter();
   
   readTemp(0); //Read the die temperature. Should report something like room Temp
   
   delay(500);
   while(1);
   
   
   enableBalancing(1, true); //test
   */
}

void loop()
{
  //Each second make a reading of cell voltages
  //And blink the status LED
  if(millis() - lastTime > 1000)
  {
    for(int i = 0 ; i < NUMBER_OF_CELLS ; i++)
      cellVoltage[i] = readCellVoltage(i);

    //Toggle stat LED
    if(digitalRead(statLED) == HIGH)
      digitalWrite(statLED, LOW);
    else
    {
      digitalWrite(statLED, HIGH);
      displayVoltages();
    }

    int temp = readTemp(0);
    Serial.print("Die temp = ");
    Serial.println(temp);

    float packV = readPackVoltage();
    Serial.print("PackV = ");
    Serial.println(packV);

    //Calc the pack voltage by hand?
    float totalVoltage = 0;
    for(int i = 0 ; i < NUMBER_OF_CELLS ; i++)
      totalVoltage += cellVoltage[i];
    Serial.print("PackV manual = ");
    Serial.println(totalVoltage);
    
  
    lastTime = millis();
  }

  //For every IRQ event read the flags and update the coulomb counter and other major events
  if(bq769x0_IRQ_Triggered == true)
  {
    //Read the status register and update if needed
    byte sysStat = registerRead(bq796x0_SYS_STAT);

    Serial.print("sysStat: 0x");
    Serial.println(sysStat, HEX);

    //Double check that ADC is enabled
    //byte sysVal = registerRead(bq796x0_SYS_CTRL1);
    //if(sysVal & bq796x0_ADC_EN)
    //{
    //  Serial.println("ADC Enabled");
    //}

    //We need to write 1s into all the places we want a zero, but not overwrite the 1s we want left alone
    byte sysNew = 0; 

    //Check for couloumb counter read
    if(sysStat & bq796x0_CC_READY)
    {
      Serial.println("CC Ready");
      totalCoulombCount += readCoulombCounter(); //Add this 250ms reading to the global fuel gauge
      sysNew |= bq796x0_CC_READY; //Clear this status bit by writing a one into this spot
    }

    if(sysStat & bq796x0_DEVICE_XREADY) //Internal fault
    {
      Serial.println("Internal fault");
      sysNew |= bq796x0_DEVICE_XREADY; //Clear this status bit by writing a one into this spot
    }

    if(sysStat & bq796x0_OVRD_ALERT) //Alert pin is being pulled high externally?
    {
      Serial.println("Override alert");
      sysNew |= bq796x0_OVRD_ALERT; //Clear this status bit by writing a one into this spot
    }

    if(sysStat & bq796x0_UV) //Under voltage
    {
      Serial.println("Under voltage alert!");
      sysNew |= bq796x0_UV; //Clear this status bit by writing a one into this spot
    }

    if(sysStat & bq796x0_OV) //Over voltage
    {
      Serial.println("Over voltage alert!");
      sysNew |= bq796x0_OV; //Clear this status bit by writing a one into this spot
    }

    if(sysStat & bq796x0_SCD) //Short circuit detect
    {
      Serial.println("Short Circuit alert!");
      //sysNew |= bq796x0_SCD; //Clear this status bit by writing a one into this spot
    }

    if(sysStat & bq796x0_OCD) //Over current detect
    {
      Serial.println("Over current alert!");
      //sysNew |= bq796x0_OCD; //Clear this status bit by writing a one into this spot
    }

    //Update the SYS_STAT with only the ones we want, only these bits will clear to zero
    registerWrite(bq796x0_SYS_STAT, sysNew); //address, value

    bq769x0_IRQ_Triggered = false; //Reset flag
  }

  if(Serial.available())
  {
    byte incoming = Serial.read();

    if(incoming == '1')
    {
      Serial.println("Entering ship mode");
      enterSHIPmode();      
    }

  }

  //Display cell voltages


  //Display CC fuel gauge
  //totalCoulomb = readCoulombCounter();

  //Display temperatures

  //Display any other register info
}

// this is irq handler for bq769x0 interrupts, has to return void and take no arguments
// always make code in interrupt handlers fast and short
void bq769x0IRQ()
{
  bq769x0_IRQ_Triggered = true;
}

//Initiates the first few I2C commands
//Returns true if we can verify communication
//Set CC_CFG to default 0x19
//Turn on the ADC
//Assume we are checking internal die temperatures (leave TEMP_SEL at zero)
//Configure the interrupts for Arduino Uno
//Read the Gain and Offset factory settings into global variables
boolean initBQ(byte irqPin)
{
  //Test to see if we have correct I2C communication
  //byte testByte = registerRead(bq796x0_OV_TRIP); //Should be something other than zero on POR
  byte testByte = registerRead(bq796x0_ADCGAIN2); //Should be something other than zero on POR

  for(byte x = 0 ; x < 10 && testByte == 0 ; x++)
  {
    Serial.print(".");
    testByte = registerRead(bq796x0_ADCGAIN2);
    delay(100);
  }
  //if(testByte == 0x00) return false; //Something is very wrong. Check wiring.

  //"For optimal performance, [CC_CFG] should be programmed to 0x19 upon device startup." page 40
  registerWrite(bq796x0_CC_CFG, 0x19); //address, value


  //Double check that ADC is enabled
  byte sysVal = registerRead(bq796x0_SYS_CTRL1);
  if(sysVal & bq796x0_ADC_EN)
  {
    Serial.println("ADC Already Enabled");
  }
  sysVal |= bq796x0_ADC_EN; //Set the ADC_EN bit
  registerWrite(bq796x0_SYS_CTRL1, sysVal); //address, value

  //Enable countinous reading of the Coulomb Counter
  sysVal = registerRead(bq796x0_SYS_CTRL2);
  sysVal |= bq796x0_CC_EN; //Set the CC_EN bit
  registerWrite(bq796x0_SYS_CTRL2, sysVal); //address, value
  //Serial.println("Coulomb counter enabled");

  //Attach interrupt
  pinMode(irqPin, INPUT); //No pull up

  if(irqPin == 2)
    //Interrupt zero on Uno is pin 2
    attachInterrupt(0, bq769x0IRQ, RISING);
  else if (irqPin == 3)
    //Interrupt one on Uno is pin 3
    attachInterrupt(1, bq769x0IRQ, RISING);
  else
    Serial.println("irqPin invalid. Alert IRQ not enabled.");

  //Gain and offset are used in multiple functions
  //Read these values into global variables
  gain = readGAIN() / (float)1000; //Gain is in uV so this converts it to mV. Example: 0.370mV/LSB
  offset = readADCoffset(); //Offset is in mV. Example: 65mV

  Serial.print("gain: ");
  Serial.print(gain);
  Serial.println("uV/LSB");

  Serial.print("offset: ");
  Serial.print(offset);
  Serial.println("mV");

  //Read the system status register
  byte sysStat = registerRead(bq796x0_SYS_STAT);
  if(sysStat & bq796x0_DEVICE_XREADY)
  {
    Serial.println("Device X Ready Error");
    //Try to clear it
    registerWrite(bq796x0_SYS_STAT, bq796x0_DEVICE_XREADY);

    delay(500);
    //Check again  
    byte sysStat = registerRead(bq796x0_SYS_STAT);
    if(sysStat & bq796x0_DEVICE_XREADY)
    {
      Serial.println("Device X Ready Not Cleared");
    }
  }

  //Set any other settings such as OVTrip and UVTrip limits
  float under = readUVtrip();
  float over = readOVtrip();

  Serial.print("Undervoltage trip: ");
  Serial.print(under);
  Serial.println("V");

  Serial.print("Overvoltage trip: ");
  Serial.print(over);
  Serial.println("V");

  if(under != 3.32)
  {
    writeUVtrip(3.32); //Set undervoltage to 3.32V
    Serial.print("New undervoltage trip: ");
    Serial.print(readUVtrip());
    Serial.println("V"); //should print 3.32V
  }

  if(over != 4.27)
  {
    writeOVtrip(4.27); //Set overvoltage to 4.27V
    Serial.print("New overvoltage trip: ");
    Serial.print(readOVtrip());
    Serial.println("V"); //should print 4.27V
  }

  return true;
}

//Pretty print the pack voltages
void displayVoltages(void)
{
  Serial.println("Voltages:");

  for(int i = 1 ; i < NUMBER_OF_CELLS + 1 ; i++)
  {
    Serial.print("[");
    Serial.print(i);
    Serial.print("]");

    Serial.print(cellVoltage[i], 2);
    Serial.print(" ");

    if(i % 5 == 0) Serial.println();
  }
}

//Enable or disable the balancing of a given cell
//Give me a cell # and whether you want balancing or not
void enableBalancing(byte cellNumber, boolean enabled)
{
  byte startingBit, cellRegister;

  if(cellNumber < 1 || cellNumber > 15) return; //Out of range

  if(cellNumber < 6)
  {
    startingBit = 0;
    cellRegister = bq796x0_CELLBAL1;
  }
  else if(cellNumber < 11)
  {
    startingBit = 6; //The 2nd Cell balancing register starts at CB6
    cellRegister = bq796x0_CELLBAL2; //If the cell number is 6-10 then we are in the 2nd cell balancing register
  }
  else if(cellNumber < 16)
  {
    startingBit = 11;
    cellRegister = bq796x0_CELLBAL3;
  }

  byte cell = registerRead(cellRegister); //Read what is currently there

  if(enabled)
    cell |= (1<<(cellNumber - startingBit)); //Set bit for balancing
  else
    cell &= ~(1<<(cellNumber - startingBit)); //Clear bit to disable balancing

  registerWrite(cellRegister, cell); //Make it so
}

//Calling this function will put the IC into ultra-low power SHIP mode
//A boot signal is needed to get back to NORMAL mode
void enterSHIPmode(void)
{
  //This function is currently untested but should work
  byte sysValue = registerRead(bq796x0_SYS_CTRL1);

  sysValue &= 0xFC; //Step 1: 00
  registerWrite(bq796x0_SYS_CTRL1, sysValue);

  sysValue |= 0x03; //Step 2: non-01
  registerWrite(bq796x0_SYS_CTRL1, sysValue);

  sysValue &= ~(1<<1); //Step 3: 01
  registerWrite(bq796x0_SYS_CTRL1, sysValue);

  sysValue = (sysValue & 0xFC) | (1<<1); //Step 4: 10
  registerWrite(bq796x0_SYS_CTRL1, sysValue);

  //bq should now be in powered down SHIP mode and will not respond to commands
  //Boot on VS1 required to start IC
}

//Given a cell number, return the cell voltage
//Vcell = GAIN * ADC(cell) + OFFSET
//Conversion example from datasheet: 14-bit ADC = 0x1800, Gain = 0x0F, Offset = 0x1E = 2.365V
float readCellVoltage(byte cellNumber)
{
  if(cellNumber < 1 || cellNumber > 15) return(-0); //Return error

  //Serial.print("Read cell number: ");
  //Serial.println(cellNumber);

  //Reduce the caller's cell number by one so that we get register alignment
  cellNumber--;

  byte registerNumber = bq796x0_VC1_HI + (cellNumber * 2);

  //Serial.print("register: 0x");
  //Serial.println(registerNumber, HEX);

  int cellValue = registerDoubleRead(registerNumber);

  //int cellValue = 0x1800; //6,144 - Should return 2.365
  //int cellValue = 0x1F10l; //Should return 3.052

  //Cell value should now contain a 14 bit value

  //Serial.print("Cell value (dec): ");
  //Serial.println(cellValue);
  
  if(cellValue == 0) return(0);

  float cellVoltage = cellValue * gain + offset; //0x1800 * 0.37 + 60 = 3,397mV
  cellVoltage /= (float)1000;

  //Serial.print("Cell voltage: ");
  //Serial.println(cellVoltage, 3);

  return(cellVoltage);
}

//Given a thermistor number return the temperature in C
//Valid thermistor numbers are 1 to 3 for external and 0 to read the internal die temp
//If you switch between internal die and external TSs this function will delay 2 seconds
int readTemp(byte thermistorNumber)
{
  //There are 3 external thermistors (optional) and an internal temp reading (channel 0)
  if(thermistorNumber < 0 || thermistorNumber > 3) return(-0); //Return error

  //Serial.print("Read thermistor number: ");
  //Serial.println(thermistorNumber);

  byte sysValue = registerRead(bq796x0_SYS_CTRL1);

  if(thermistorNumber > 0)
  {
    //See if we need to switch between internal die temp and external thermistor
    if((sysValue & bq796x0_TEMP_SEL) == 0)
    {
      //Bad news, we have to do a switch and wait 2 seconds
      //Set the TEMP_SEL bit
      sysValue |= bq796x0_TEMP_SEL;
      registerWrite(bq796x0_SYS_CTRL1, sysValue); //address, value

        Serial.println("Waiting 2 seconds to switch thermistors");
      delay(2000);      
    }

    int registerNumber = bq796x0_TS1_HI + ((thermistorNumber - 1) * 2);
    int thermValue = registerDoubleRead(registerNumber);

    //Therm value should now contain a 14 bit value

    Serial.print("Therm value: 0x");
    Serial.println(thermValue, HEX); //0xC89 = 3209

    float thermVoltage = thermValue * (float)382; //0xC89 * 382 = 1,225,838uV. 0x233C * 382uV/LSB = 3,445,640uV
    thermVoltage /= (float)1000000; //Convert to V
    
    Serial.print("thermVoltage: ");
    Serial.println(thermVoltage, 3);

    float thermResistance = ((float)10000 * thermVoltage) / (3.3 - thermVoltage);

    Serial.print("thermResistance: ");
    Serial.println(thermResistance);

    //We now have thermVoltage and resistance. With a datasheet for the NTC 103AT thermistor we could
    //calculate temperature. 
    int temperatureC = thermistorLookup(thermResistance);

    Serial.print("temperatureC: ");
    Serial.println(temperatureC);

    return(temperatureC);
  }
  else if(thermistorNumber == 0)
  {
    //See if we need to switch between internal die temp and external thermistor
    if((sysValue & 1<<3) != 0)
    {
      //Bad news, we have to do a switch and wait 2 seconds
      //Clear the TEMP_SEL bit
      sysValue &= ~(1<<3);
      registerWrite(bq796x0_SYS_CTRL1, sysValue); //address, value

        Serial.println("Waiting 2 seconds to switch to internal die thermistors");
      delay(2000);      
    }

    int thermValue = registerDoubleRead(bq796x0_TS1_HI); //There are multiple internal die temperatures. We are only going to grab 1.

    //Therm value should now contain a 14 bit value
    //Serial.print("Therm value: 0x");
    //Serial.println(thermValue, HEX);

    float thermVoltage = thermValue * (float)382; //0xC89 * 382 = 1,225,838uV. 0x233C * 382uV/LSB = 3,445,640uV
    thermVoltage /= (float)1000000; //Convert to V
    
    //Serial.print("thermVoltage: ");
    //Serial.println(thermVoltage, 3);

    float temperatureC = 25.0 - ((thermVoltage - 1.2) / 0.0042);

    //Serial.print("temperatureC: ");
    //Serial.println(temperatureC);
    
    //float temperatureF = (temperatureC * ((float)9/5)) + 32;

    //Serial.print("temperatureF: ");
    //Serial.println(temperatureF);
    
    return((int)temperatureC);
  }

}

//Returns the coulomb counter value in microVolts
//Example: 84,400uV 
//Coulomb counter is enabled during bqInit(). We do not use oneshot.
//If the counter is enabled in ALWAYS ON mode it will set the ALERT pin every 250ms. You can respond to this however you want.
//Host may clear the CC_READY bit or let it stay at 1.
float readCoulombCounter(void)
{
  int count = registerDoubleRead(bq796x0_CC_HI);

  //int count = 0xC350; //Test. Should report -131,123.84

  float count_uV = count * 8.44; //count should be naturally in 2's compliment. count_uV is now in uV

  return(count_uV);
}

//Returns the pack voltage in volts
//Vbat = 4 * GAIN * ADC(cell) + (# of cells * offset)
float readPackVoltage(void)
{
  unsigned int packADC = registerDoubleRead(bq796x0_BAT_HI);

  //Serial.print("packADC = ");
  //Serial.println(packADC);

  //packADC = 0x6DDA; //28,122 Test. Should report something like 42.520V
  
  //packADC = 35507
  //gain = 0.38uV/LSB
  //offset = 47mV
  //53970 
  float packVoltage = 4 * gain * packADC; //53970 in uV?
  packVoltage += (NUMBER_OF_CELLS * offset); //Should be in mV

  return(packVoltage / (float)1000); //Convert to volts
}

//Reads the gain registers and calculates the system's factory trimmed gain
//GAIN = 365uV/LSB + (ADCGAIN<4:0>) * 1uV/LSB
//ADC gain comes from two registers that have to be moved around and combined.
int readGAIN(void)
{
  byte val1 = registerRead(bq796x0_ADCGAIN1);
  byte val2 = registerRead(bq796x0_ADCGAIN2);
  val1 &= 0b00001100; //There are some unknown reservred bits around val1 that need to be cleared

  //Recombine the bits into one ADCGAIN
  byte adcGain = (val1 << 1) | (val2 >> 5);

  int gain = 365 + adcGain;

  return(gain);
}

//Returns the factory trimmed ADC offset
//Offset is -127 to 128 in mV
int readADCoffset(void)
{
  //Here we need to convert a 8bit 2's compliment to a 16 bit int
  char offset = registerRead(bq796x0_ADCOFFSET);

  return((int)offset); //8 bit char is now a full 16-bit int. Easier math later on.
}

//Returns the over voltage trip threshold
//Default is 0b.10.OVTRIP(0xAC).1000 = 0b.10.1010.1100.1000 = 0x2AC8 = 10,952
//OverVoltage = (OV_TRIP * GAIN) + ADCOFFSET
//Gain and Offset is different for each IC
//Example: voltage = (10,952 * 0.370) + 56mV = 4.108V
float readOVtrip(void)
{
  int trip = registerRead(bq796x0_OV_TRIP);

  trip <<= 4; //Shuffle the bits to align to 0b.10.XXXX.XXXX.1000
  trip |= 0x2008;

  float overVoltage = ((float)trip * gain) + offset;
  overVoltage /= 1000; //Convert to volts

  //Serial.print("overVoltage should be around 4.108: ");
  //Serial.println(overVoltage, 3);

  return(overVoltage);
}

//Given a voltage (4.22 for example), set the over voltage trip register
//Example: voltage = 4.2V = (4200mV - 56mV) / 0.370mv = 11,200
//11,200 = 0x2BC0 = 
void writeOVtrip(float tripVoltage)
{
  byte val = tripCalculator(tripVoltage); //Convert voltage to an 8-bit middle value
  registerWrite(bq796x0_OV_TRIP, val); //address, value
}

//Returns the under voltage trip threshold
//Default is 0b.01.UVTRIP(0x97).0000 = 0x1970 = 6,512
//UnderVoltage = (UV_TRIP * GAIN) + ADCOFFSET
//Gain and Offset is different for each IC
//Example: voltage = (6,512 * 0.370) + 56mV = 2.465V
float readUVtrip(void)
{
  int trip = registerRead(bq796x0_UV_TRIP);

  trip <<= 4; //Shuffle the bits to align to 0b.01.XXXX.XXXX.0000
  trip |= 0x1000;

  float underVoltage = ((float)trip * gain) + offset;
  underVoltage /= 1000; //Convert to volts

  //Serial.print("underVoltage should be around 2.465: ");
  //Serial.println(underVoltage, 3);

  return(underVoltage);
}

//Given a voltage (2.85V for example), set the under voltage trip register
void writeUVtrip(float tripVoltage)
{
  byte val = tripCalculator(tripVoltage); //Convert voltage to an 8-bit middle value
  registerWrite(bq796x0_UV_TRIP, val); //address, value
}

//Under voltage and over voltage use the same rules for calculating the 8-bit value
//Given a voltage this function uses gain and offset to get a 14 bit value
//Then strips that value down to the middle-ish 8-bits
//No registers are written, that's up to the caller
byte tripCalculator(float tripVoltage)
{
  tripVoltage *= 1000; //Convert volts to mV

  //Serial.print("tripVoltage to be: ");
  //Serial.println(tripVoltage, 3);

  tripVoltage -= offset;
  tripVoltage /= gain;

  int tripValue = (int)tripVoltage; //We only want the integer - drop decimal portion.

  //Serial.print("tripValue should be something like 0x2BC0: ");
  //Serial.println(tripValue, HEX);

  tripValue >>= 4; //Cut off lower 4 bits
  tripValue &= 0x00FF; //Cut off higher bits

  //Serial.print("About to report tripValue: ");
  //Serial.println(tripValue, HEX);

  return(tripValue);
}

//Write a given value to a given register
void registerWrite(byte regAddress, byte regData)
{
  Wire.beginTransmission(bqI2CAddress);
  Wire.write(regAddress);
  Wire.endTransmission();

  Wire.beginTransmission(bqI2CAddress);
  Wire.write(regAddress);
  Wire.write(regData);
  Wire.endTransmission();
}

//Returns a given register
byte registerRead(byte regAddress)
{
  Wire.beginTransmission(bqI2CAddress);
  //Here's where I2C can time out
  Wire.write(regAddress);
  Wire.endTransmission();

  Wire.requestFrom(bqI2CAddress, 1);
  
  /*byte counter = 0;
  while(Wire.available() == 0)
  {
    delay(1);
    if(counter++ > 250) return(0); //Return with error
  }*/

  return(Wire.read());
}
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

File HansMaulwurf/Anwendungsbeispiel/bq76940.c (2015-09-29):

uint8_t bq76940_init(void)
{
	uint8_t error = 0;

// make sure the bq is booted up--->set TS1 to 3.3V and back to VSS
// maybe set temp-mode for internal or external temp here

	// enable ADC
	error |= registerWrite(SYS_CTRL1, ADC_EN);
	// check if ADC is active
	if(!(registerRead(SYS_CTRL1) & ADC_EN)) { return ERROR_ADC; }

	// write 0x19 to CC_CFG according to datasheet page 39
	error |= registerWrite(CC_CFG, 0x19);

	gain = gainRead();      				// get gain
	if( (gain<365) | (gain>396) ) { return ERROR_GAIN; };	// check gain

	offset = offsetRead();  // get offset
	// if( (offset<0x00) | (offset>0xFF) ) { return 1; };	// dont check offset

	error |= UVtripWrite();	// write OV_TRIP
	error |= OVtripWrite();	// write UV_TRIP

// für 30 A Hauptschalter // Versuchszwecke
//	error |= registerWrite(PROTECT1, 0x00);	// write PROTECT1
//	error |= registerWrite(PROTECT2, 0x00);	// write PROTECT2
//	error |= registerWrite(PROTECT3, 0x50);	// write PROTECT3

// für 190 A Hauptschalter
	error |= registerWrite(PROTECT1, 0x0B);	// write PROTECT1
	error |= registerWrite(PROTECT2, 0x9C);	// write PROTECT2
	error |= registerWrite(PROTECT3, 0x50);	// write PROTECT3

	// clear SYS-STAT for init
	if( registerRead(SYS_STAT) ) { checkSTAT(); }

	// doublecheck if bq is ready
	if(registerRead(SYS_STAT) & DEVICE_XREADY)
	{
		// DEVICE_XREADY is set
		// write 1 in DEVICE_XREADY to clear it
		error |= registerWrite(SYS_STAT, DEVICE_XREADY);
		// check again
		if(registerRead(SYS_STAT) & DEVICE_XREADY) { return ERROR_XREADY; }
	}

	// enable countinous reading of the Coulomb Counter
//	error |= registerWrite(SYS_CTRL2, CC_EN);	// sets ALERT at 250ms interval to high


	return error; // 0 if successful
}

uint8_t enterShipMode(void)
{
	uint8_t error = 0;
	uint8_t ctrl1 = registerRead(SYS_CTRL1);

	// clear SHUT_A and SHUT_B
	ctrl1 &= 0xFC;
	error |= registerWrite(SYS_CTRL1, ctrl1);

	// SHUT_A=0, SHUT_B=1
	ctrl1 |= 0x01;
	error |= registerWrite(SYS_CTRL1, ctrl1);

	// SHUT_A=1, SHUT_B=0
	ctrl1 |= 0x01;
	error |= registerWrite(SYS_CTRL1, ctrl1);

	return error; // 0 if successful
}

uint16_t gainRead(void)
{
	uint8_t reg1 = registerRead(ADCGAIN1);
	uint8_t reg2 = registerRead(ADCGAIN2);

	reg1 &= 0b00001100;

	return (365 + ((reg1 << 1)|(reg2 >> 5)));
}

int8_t offsetRead(void)
{
	return registerRead(ADCOFFSET);
}

uint16_t PackVoltageRead(void)
{
	uint32_t packADC = registerDoubleRead(BAT_HI);

	return (((4*gain*(packADC))/1000)+(NUMBER_OF_CELLS*offset));	// Cellstack Voltage in mV
}

uint16_t CellVoltageRead(uint8_t cellregister) // need VCX_HI !!!!!
{
	uint32_t cellADC = 0;

	cellADC = registerDoubleRead(cellregister);

	return (((cellADC*gain)/1000)+offset);				// returns voltage in mV
}

uint8_t CellArrayVoltageRead(uint16_t cellV[])
{
	uint8_t i=0;
	uint8_t error=0;

	error=registerArrayRead(VC1_HI, cellV, NUMBER_OF_CELLS);

	for(;i<NUMBER_OF_CELLS;i++)
	{
		cellV[i] = ((((uint32_t)cellV[i]*gain)/1000)+offset);
	}

	return error;
}

//calculates a Voltage back in ADC and strips the middle 8-Bits
uint8_t tripCalculator(uint32_t thershold)
{
	thershold -= offset;
	thershold *= 1000;
	thershold /= gain;
	thershold++;		//Nachkommastellenkorrektur
	thershold >>= 4;

	return ((uint8_t)thershold);
}

uint8_t OVtripWrite(void)
{
	return ( registerWrite(OV_TRIP, tripCalculator(OV_THERSHOLD)) ); // 0 => successful
}

uint8_t UVtripWrite(void)
{
	return ( registerWrite(UV_TRIP, tripCalculator(UV_THERSHOLD)) ); // 0 => successful
}

// measures one of the 4 Tempsensors(1xint., 3xext.)
// number: 0 for internal, 1 for TS1, 2 for TS2 and 3 for TS3
// TEMP_SEL: internal=0, external=1
// notice that a 2-s delay is needed by switching internal and external
int16_t TempRead(uint8_t number)
{
	uint8_t ctrl1 = (registerRead(SYS_CTRL1));
	int32_t temp = 0;

	// calc internal temp
	if(number == 0)
	{
		// check if TEMP_SEL=1 for externel-mode, then clear TEMP_SET and wait
		if(ctrl1 & TEMP_SEL) { registerWrite(SYS_CTRL1, (ctrl1 & ~(TEMP_SEL)) ); _delay_ms(2000); }

		// read tempADC
		temp = registerDoubleRead(TS2_HI);

		// real: -60°C..150°C in (return:) -6000c°C..15000c°C [DS_S.24]
		return (25000-((((temp*382)/1000)-1200)*238))/10;
	}

	// calc externel temp
	// check if TEMP_SEL=0 for internel-mode, then set TEMP_SET and wait
	if( !(ctrl1 & TEMP_SEL) ) { registerWrite(SYS_CTRL1, (ctrl1  | (TEMP_SEL)) ); _delay_ms(2000); } // wait for update

	// read tempADC
	temp = registerDoubleRead(TS1_HI+2*(number-1));

	// calc R_TS [DS_S.23]
	temp = (temp*382)/1000;		// mV
	temp = (10000*temp)/(3300-temp);// V/A
	temp = RtoT((uint16_t)temp);

	// return TSX in °C in 5°C-Schritten
	return temp;
}

int16_t CurrentRead(void)
{
	int16_t cur = registerDoubleRead(CC_HI);

	cur = ((int32_t)cur*(844/R_SHUNT))/100;

	//measurement area: -327.68A..327.67A // Gültigkeitsbereich(return): -32768cA..32767cA // Auflösung: 30mA
	return cur;
	// 8.44µV=844cµV
	// I=U/R=cµV/(µV/A)=CµVA/µV=cA
}

// checks BalancingBits(5-Bitregister) in 3x 5er-Gruppen
// erlaubte Registerkombinationen(dez.): 1 2 4 5 8 9 10 12 16 17 18 20 21 24 25 (Cell1:2^0; Cell2:2^1; Cell3:2^2....)
// return:
// 1: Fehler Bitkombination im Register unsicher
// 0: Bitkombination ist sicher
uint8_t BalancRegCheck(uint8_t bal_reg)
{
	if( ((bal_reg <= 5) | (!(bal_reg <= 7) & (bal_reg <= 10)) | ((bal_reg >= 16) & !(bal_reg > 25)) | (bal_reg == 12) ))
	{
		if((bal_reg == 3) | (bal_reg == 19) | (bal_reg == 23) | (bal_reg == 22)) { return 1; }
		else { return 0; }
	}
	return 1;
}

//splits unsafe Reg-combos in 2 x 8-Bit Register
//return: 5(-Bit=Reg1) + 5(LSB=Reg2) = 16-Bit = 0000001111122222
uint16_t BalancRegSplit(uint16_t bal_reg)
{
        return ( ((bal_reg & (1 << 4) ) << 5) | ((bal_reg & (1 << 2) ) << 5) | ((bal_reg & (1 << 0) ) << 5) ) | (bal_reg & (1 << 3)) | (bal_reg & (1 << 1) );
}

uint16_t Balancing(uint16_t cellV[NUMBER_OF_CELLS])
{
	uint8_t f=0, eps=ZUELS, finish=0, error=1;
	uint8_t bal_reg1, bal_reg2, bal_reg3, bal_reg10=0, bal_reg20=0, bal_reg30=0;
	uint16_t celllow=0, cellbal=0, bal_reg = 0;
	int16_t temp=0;

	// get all Cellvoltages
	CellArrayVoltageRead(cellV);

	celllow = cellV[0];
	// find cell with the lowest voltage
	for(f=1;f<NUMBER_OF_CELLS;f++) { if(cellV[f] < celllow) { celllow = cellV[f]; } }

	// check if one or more cells are at ZLSS+eps
	for(f=0;f<NUMBER_OF_CELLS;f++) { finish += (cellV[f] >= ZLSS+eps); }
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

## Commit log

2014-09-08 Initial commit
    Breakout for the BQ76940 battery monitor.
    [BLE-BMS.brd, BLE-BMS.sch]
2014-10-29 Firmware, test pack layouts.
    Firmware is mostly working! Layouts are pretty good.
    [18650 Test.brd, 18650 Test.sch, BLE-BMS.brd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]
2014-11-15 v2 with Charge/Discharge MOSFET control and cell balancing
    Many changes. Added large MOSFETs and pack interface circuitry. Added
    small MOSFETs for individual cell balancing/charging. Corrected
    Thermistor pull down error. All FPs pass 1:1 check.
    [18650 Test.brd, 18650 Test.sch, BLE-BMS.brd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]
2014-11-15 Adding assembled v1 image
2014-11-15 Adding photos and updating readme.
    [BLE-BMS.brd]

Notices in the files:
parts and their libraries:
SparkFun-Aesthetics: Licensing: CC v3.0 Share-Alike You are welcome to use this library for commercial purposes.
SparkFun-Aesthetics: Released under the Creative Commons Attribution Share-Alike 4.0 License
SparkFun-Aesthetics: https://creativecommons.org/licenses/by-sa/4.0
